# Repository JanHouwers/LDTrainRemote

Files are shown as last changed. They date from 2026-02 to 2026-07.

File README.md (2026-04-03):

# LEGO Duplo Train Remote Control

A custom remote control for the Lego duplo 10427 train, built with a Seeed Studio XIAO ESP32S3 microcontroller. Designed for and tested with the **LEGO DUPLO Train set 10427**. Connects to the train over BLE using raw NimBLE and the LEGO Wireless Protocol 3 (LWP3).

## Hardware

- **Board:** Seeed Studio XIAO ESP32S3
- **Potentiometer** on GPIO2 (D1) for variable speed control
- **4 push buttons** (active low, using internal pull-ups):

| GPIO | Pin | Function |
|---|-----|---|
| 3 | D2  | Water/action sound cycle |
| 4 | D3  | Horn |
| 5 | D4  | Stop (brake) |
| 6 | D5  | LED color cycle |

## Features

- **Variable speed** — potentiometer maps linearly to 0-100% forward or backward, with a 15% deadband around center for stop
- **11 LED colors** — cycle through off, white, green, yellow, light blue, dark blue, purple, purple pink, light pink, red pink, red
- **7 action sounds** — cycle through recorded sound, cat, nothing, beach, rain, birthday, night
- **Horn** — plays the train horn sound
- **Stop button** — immediately stops the motor
- **Auto-reconnect** — automatically scans and reconnects when the train is turned off and back on
- **Debounced buttons** — using the Bounce2 library

## Building & Uploading

Requires [PlatformIO](https://platformio.org/).

```bash
# Compile
pio run

# Upload to board
pio run -t upload

# Serial monitor
pio device monitor
```

## Dependencies

- [NimBLE-Arduino](https://github.com/h2zero/NimBLE-Arduino) 2.x — BLE stack
- [Bounce2](https://github.com/thomasfredericks/Bounce2) — button debouncing

## Configuration

Pin assignments, potentiometer deadband, speed limits, and timing are all configurable in `config.h`.

## Protocol

Communicates with the Duplo Train Hub using raw LEGO Wireless Protocol 3 (LWP3) packets over BLE:
- **Service UUID:** `00001623-1212-efde-1623-785feabcd123`
- **Characteristic UUID:** `00001624-1212-efde-1623-785feabcd123`
- **Motor packet format (11 bytes):** `0B 00 81 34 11 51 01 [CMD] 01 [SPEED] 00`
  - CMD: `01`=forward, `02`=backward, `03`=stop, `04`=LED, `06`=action, `07`=horn

## Acknowledgments

This project is based on the excellent work by [drndos](https://github.com/drndos) and his [duplo-train-controller](https://github.com/drndos/duplo-train-controller). Many thanks for figuring out the BLE protocol, the raw LWP3 packet format, and providing a working NimBLE implementation that made this project possible!

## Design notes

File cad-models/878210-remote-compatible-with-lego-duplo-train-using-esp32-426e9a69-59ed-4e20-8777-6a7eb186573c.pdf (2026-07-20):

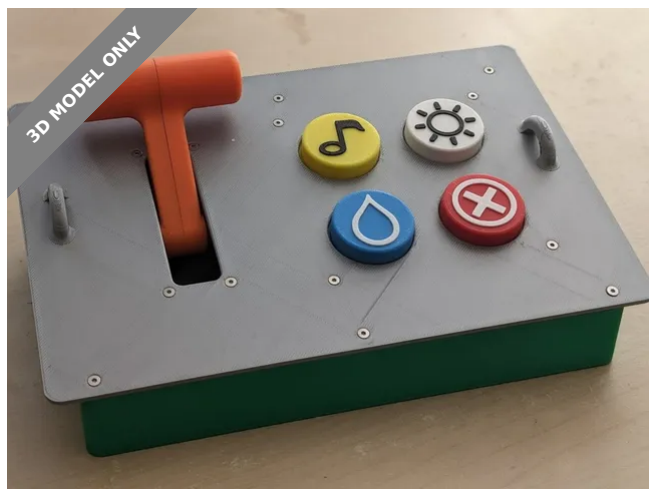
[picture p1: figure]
3D MODEL ONLY

## Summary

Remote compatible with Lego Duplo Train Introduction This project is an adaptation of the work by James Clarke, as...

Toys & Games (https://printables.com/model?categoryId=30) > Building Toys (https://printables.com/model?categoryId=37)

Tags: | duplo | lego | remotecontrol | legocompatible | legoduplo
duplotrain | legoduplotrain

Remote compatible with Lego Duplo Train
Introduction

This project is an adaptation of the work by James Clarke, as showcased on Instructables: https://www.instructables.com/Wooden-Bluetooth-Remotefor-Lego-Duplo-Train/ (https://www.instructables.com/Wooden-Bluetooth-Remote-for-Lego-Duplo-Train/)

I appreciate and thank him for the great idea that inspired this project.

The Lego Duplo Train Remote is a fantastic way to engage with and enjoy the Lego Duplo Train.

Mav_ (https://printables.com/@Mav__1866170)

## Remote compatible with Lego Duplo Train using ESP32

VIEW IN BROWSER (https://printables.com/model/878210-remote-compatible-with-lego-duplo-train-using-esp3)

updated 2. 12. 2024 | published 2. 12. 2024

Custom Section

Step 1:
Electronics and additional parts you need for this project:

1x ESP32 with 18650 Battery holder (ESP-Wroom-ESP32 NOT ESPWROOM-02) https://www.walmart.com/ip/ESP32-WiFi-Bluetooth-Development-Board-Small-IoT-Device-Compatible-With-18650-Battery-For-Programming-Projects-Wireless-Communication-Modu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 (https://www.walmart.com/ip/ESP32-WiFi-Bluetooth-Development-Board-Small-IoT-Device-Compatible-With-18650-Battery-For-Programming-Projects-Wireless-Communicati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)

4x Tactile Push Buttons 12x12x7.3mm https://www.amazon.com/TWTADE-Momentary-Tactile-Button-12x12x12mm/dp/B07CG7VTGD/ref=sr_1_5 (https://www.amazon.com/TWTADE-Momentary-Tactile-Button-12x12x12mm/dp/B07CG7VTGD/ref=sr_1_5)

1x Potentiometer 10k Ohm https://www.amazon.com/HiLetgo-Single-Joint-Potentiometer-Variable-Resistors/dp/B00MCK7JMS/ref=sr_1_1_sspa (https://www.amazon.com/HiLetgo-Single-Joint-Potentiometer-Variable-Resistors/dp/B00MCK7JMS)

Set of Electric wires https://www.amazon.com/StrivedayTM-Flexible-Silicone-electronic-electrics/dp/B01LH1FYR4/ref=sr_1_1_sspa (https://www.amazon.com/StrivedayTM-Flexible-Silicone-electronic-electrics/dp/B01LH1FYR4)

18x melting Nuts m2 3.5mm in diameter (3.2 might also work) https://www.amazon.com/WALENI-Knurled-Injection-Embedment-Insertion/dp/B0CC8BZHZL/ref=sr_1_5?th=1 (https://www.amazon.com/WALENI-Knurled-Injection-Embedment-Insertion/dp/B0CC8BZHZL/ref=sr_1_5?th=1)

18 m2 x 6mm countersunk head screws https://www.amazon.com/Hilitchi-210-Piece-Metric-Countersunk-Assortment/dp/B06Y3M62Z8/ref=sr_1_6 (https://www.amazon.com/Hilitchi-210-Piece-Metric-Countersunk-Assortment/dp/B06Y3M62Z8/ref=sr_1_6)

1 Power Switch https://www.amazon.de/dp/B08CY41YT5?ref=ppx_yo2ov_dt_b_product_details&th=1 (https://www.amazon.de/dp/B08CY41YT5?ref=ppx_yo2ov_dt_b_product_details&th=1)

the size of power switches varies ... so you might need to update the body STL for the right size. I ordered these in Germany the hole in the body STL is 12 * 19 mm.

Other:

Some glue for the throttle stick (optional)

Small piece of perfboard (optional)

Some shrink tubing (recommended)

Filament:

I used PLA in 8 different colors:

- Green for the housing,

Silver top plate,
Red for the Stop push button (with white),
Blue for the Steam/Water push button (with white) Yellow for the Horn/Music push button (with black), White for the Light push button ( with black)
Black for holders (buttons and throttle lever holder), Orange for the throttle lever

In addition you need:

a soldering iron with solder,
the right screwdriver for the m2 screws
some tools to cut the cables and to strip the cables insulation.
Step 2:
3D Print all parts

Print all the parts in the color of your choice.

Please note that the throttle stick needs to be printed twice, while all other parts only need to be printed once.

All Parts

Step 3:
Soldering the ElectronicsSolder ground:

You will need 5 ground connections: 4 for the buttons and 1 for the potentiometer. Locate the ground pin on your ESP32 board and solder a small cable, around 5-10 cm in length, to it. Connect the other end of this cable to a piece of perfboard where you will solder an additional 5 cables, each around 10-20 cm in length.

(Another solution would be to daisy chain the ground cable: ESP32 GND -> potentiometer GND -> Button 1 GND -> Button 2 GND, and so on.)

PICTURE SOLDER Power Switch

GND cable harness

GND to ESP32
Solder GPIOs

Solder 6 cables, each approximately 15-25 cm in length, to the following ESP32 pins:

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
Pin 25: Button 1 (Yellow)

Pin 26: Button 2 (White)

Pin 27: Button 3 (Blue)

Pin 14: Button 4 (Red)

Pin 15: Potentiometer Data (Green)

VCC: Potentiometer + (Red)

... and connect them

*I have matched the colors of the buttons for a clear view, but you can use any colors you prefer.

Buttons & Poti

GPIO soldering
Power Switch:

Before soldering, it is important to either attach the power switch directly to the 3D printed body or use ferrules that fit the power switch.

Power Switch: On the side of the ESP32 board, there is a power switch attached. To bypass it, you need solder the new Power Switch to the left pin (ON) and the middle pin. Make sure to leave the switch on the board in the off position. A cable length of approximately 25 cm will be sufficient.

power switch

Power Switch soldering

Step 4:
Assemble all parts.Inserting Melting Nuts:

To assemble the body, you will need to fuse in a total of 10 melting nuts. Six of these nuts are used to connect the top plate, while the remaining four are for attaching the ESP32. Additionally, the button holder requires four melting nuts to be attached to the top plate as well as the Throttle sick holder.

Melt Nuts

Melt Nuts

ESP32:

Screw the ESP32 onto the body.

Optional: Attach 18650 battery to ESP32 board.
Throttle Assembly:

Begin by inserting the potentiometer into the throttle stick holder. Ensure that the potentiometer is set to the middle position, although adjustments may be necessary in the software.
Next, insert the right part of the throttle stick and connect it with the potentiometer. Pass throttle stick through the top plate throttle stick hole.
The left throttle stick may require a bit more effort and force to insert, also pass it though the top plate. The Holder will need to stretch a bit. Optionally, connect the stick halves with a small bar and consider using glue to secure them together.
Screw the holder onto the top plate.

Poti

Throttle Stick #1

Throttle Stick #2

Throttle Stick #3
Button Assembly:

The push buttons need to be placed on top of the button plate. Thread the buttons through the holes in the plate. In this step, you need to determine the correct placement for each button
Connect the 3D printed buttons to the push buttons.
Screw the button plate onto the top plate.

Buttons

Buttons

Hardware Finished

Step 5:
Flash the Software

To flash the software onto the ESP32, follow these steps:

Download the software from GitHub. You can find it here. (https://github.com/mav00/LDTrainRemote)

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
## Model files

The software requires the Leguino Library, which you can download from here. (https://github.com/corneliusmunz/legoino?tab=readme-ov-file)
Additionally, the software requires the Button2 Library, which doesn't need to be downloaded separately.
You have two options to flash the software: PlatformIO or Arduino IDE.

PlatformIO:

Install PlatformIO plugin in Visual Studio Code (Picture1)
Restart Visual Studio Code when everything is finished (Picture2) Pick the LDTTRAINREMOTE Folder ( not the SRC folder but the folder above)
Copy legoino-master into a fresh created "lib" folder next to the src folder (Picture3)
check spelling legoino-master in platformio.ini file ... sorry I will update the code (Picture3)
VS Code will install some prerequisites- wait until it is finished ... takes about (Picture4)
goto src / main.cpp hit build (the check icon in the lower bar) upload the code with the -> icon
Step 6:
Enjoy ...Activate the Remote:

Power up the Train. The Lego Duplo Train searches for Bluetooth connection for about 20 seconds after powering up
Start the Remote by switching it on.
The train will give a sound when it is successfully connected to the remote.

Category: Toy & Game Accessories

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
rldt_-_button_light_v10.stl

rldt_-_throttle_stick_holder_v10.stl

Find source .stl files on Thingiverse.com (https://www.thingiverse.com/thing:6620027) rldt_-_button_water_v10.stl

rldt_-_throttle_stick_v10.stl

rldt_-__button_holder_v10.stl

rldt_-_body_v10.stl

rldt_-_throttle_stick_connection_rod_v10.stl

rldt_-_button_stop_v10.stl

rldt_-_button_music_v10.stl

rldt_-_topplate_v10.stl

## License

This work is licensed under a
Creative Commons (4.0 International License)

Attribution—Noncommercial—Share Alike (http://creativecommons.org/licenses/by-nc-sa/4.0/)

✖ | Sharing without ATTRIBUTION
✔ | Remix Culture allowed
✖ | Commercial Use
✖ | Free Cultural Works
✖ | Meets Open Definition

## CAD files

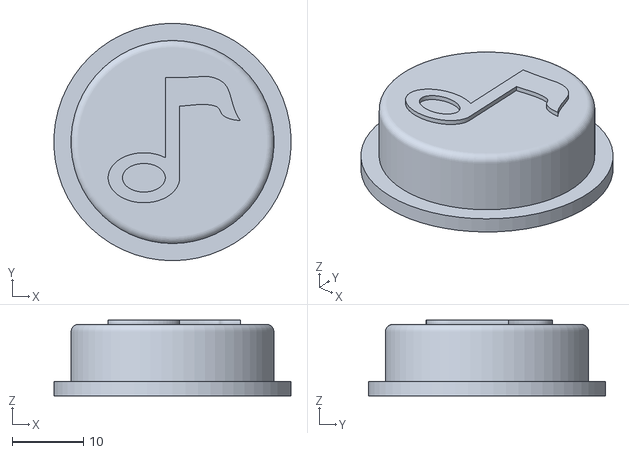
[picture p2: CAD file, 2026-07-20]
cad-models/rldt_-_button_music_v10.stl
33.2 x 33.2 x 10.6

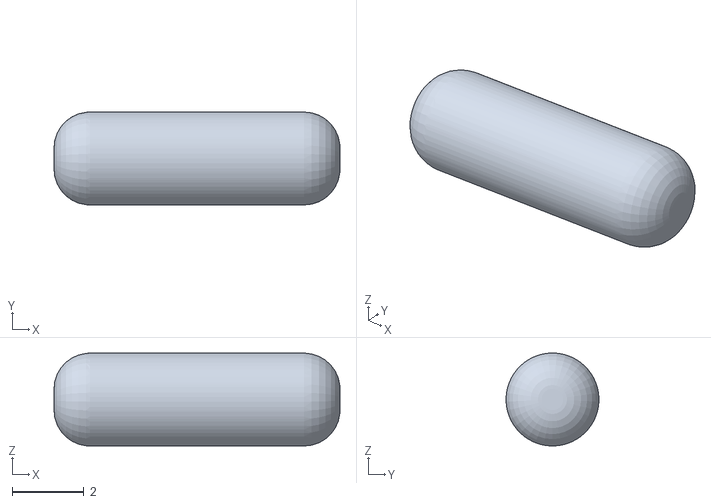
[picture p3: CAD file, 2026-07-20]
cad-models/rldt_-_throttle_stick_connection_rod_v10.stl
8.00 x 2.60 x 2.60

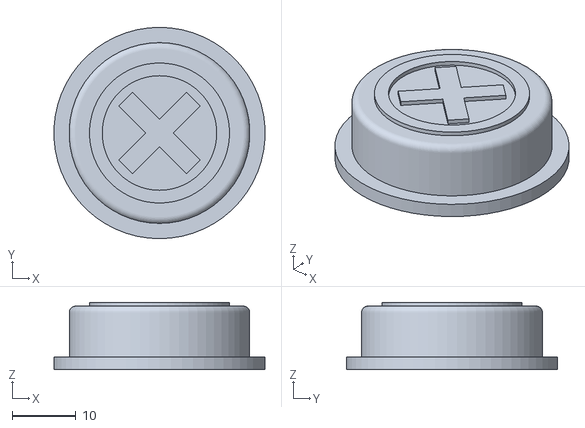
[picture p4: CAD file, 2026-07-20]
cad-models/rldt_-_button_stop_v10.stl
33.2 x 33.2 x 10.6

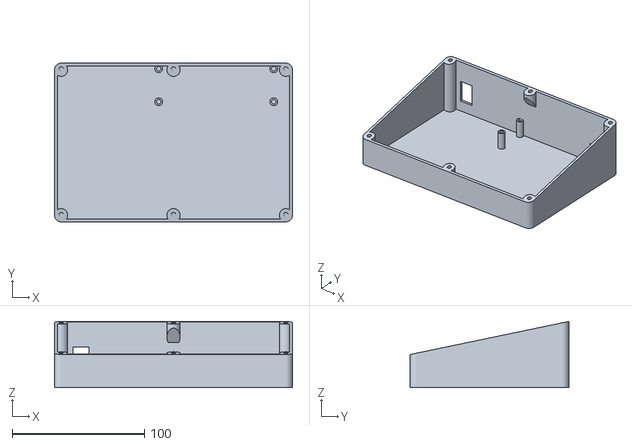
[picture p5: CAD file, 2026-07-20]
cad-models/rldt_-_body_v10.stl
180.0 x 120.0 x 50.0

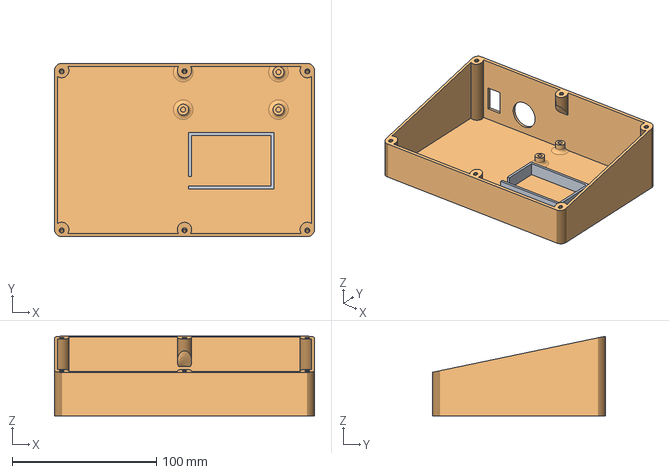
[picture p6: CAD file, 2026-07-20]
cad-models/BOX SC V2.stp
180.0 x 120.0 x 55.1 mm
Design1
rldt_-_body_v10

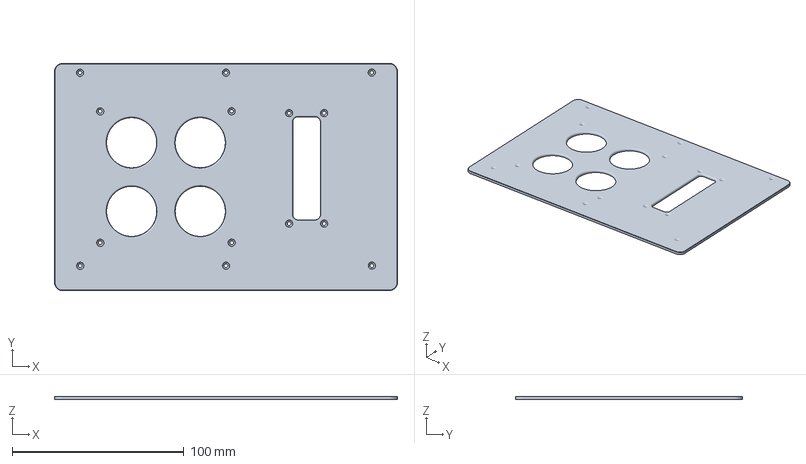
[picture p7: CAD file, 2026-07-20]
cad-models/topplaat.scdocx.3mf
199.9 x 132.5 x 2.00 mm

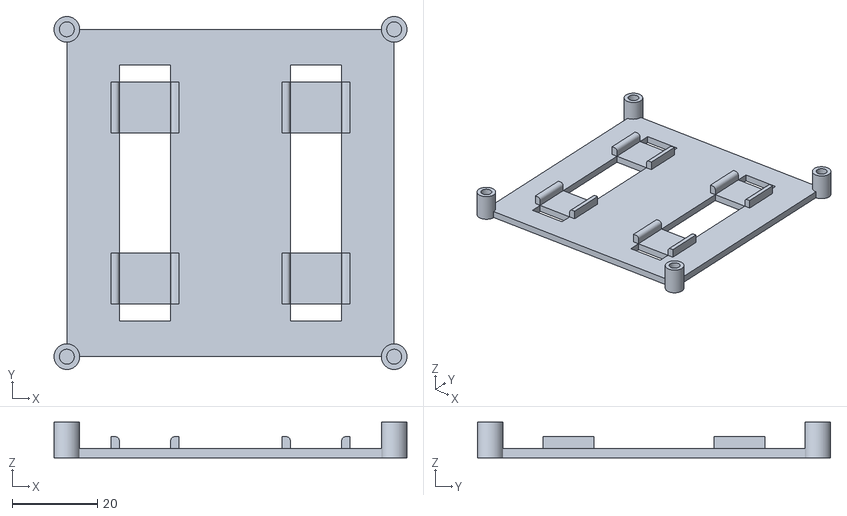
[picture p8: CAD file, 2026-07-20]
cad-models/rldt_-__button_holder_v10.stl
82.6 x 82.6 x 8.40

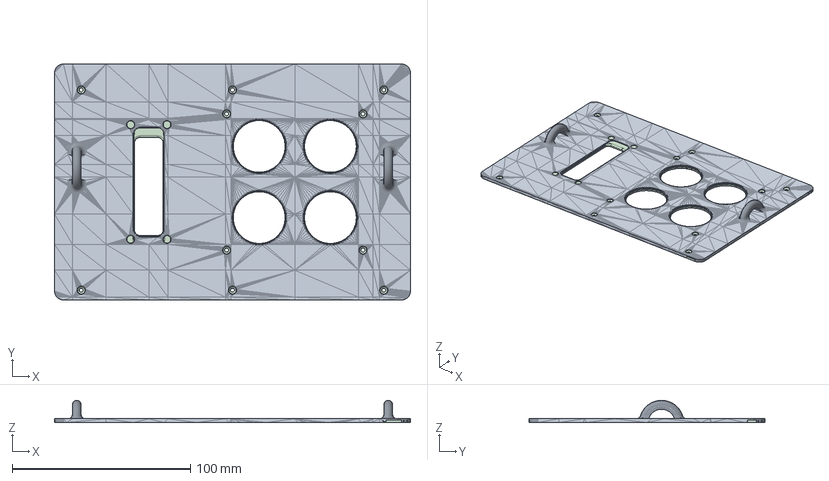
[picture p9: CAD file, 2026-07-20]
cad-models/Topplaat.stp
200.0 x 132.6 x 12.5 mm
Design2
rldt_-_topplate_v10
Topplaat

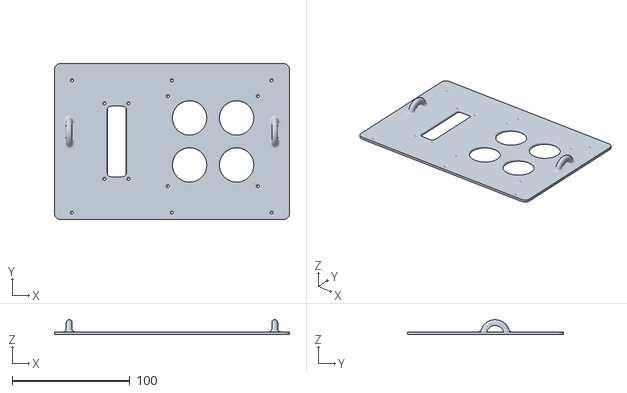
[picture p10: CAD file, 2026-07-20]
cad-models/rldt_-_topplate_v10.stl
200.0 x 132.6 x 12.5

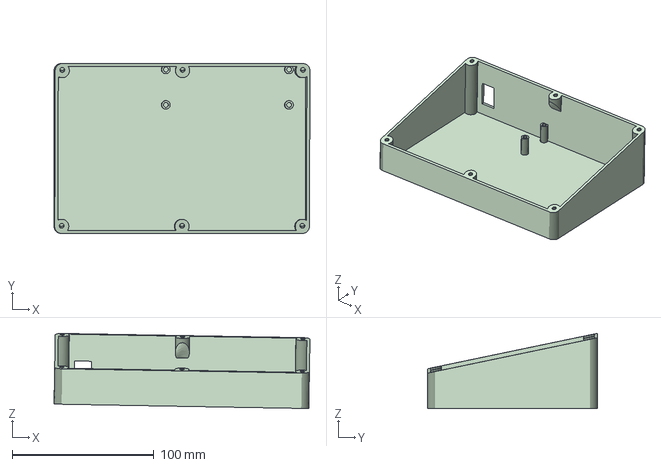
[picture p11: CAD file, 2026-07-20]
cad-models/box.stp
180.8 x 120.0 x 53.0 mm

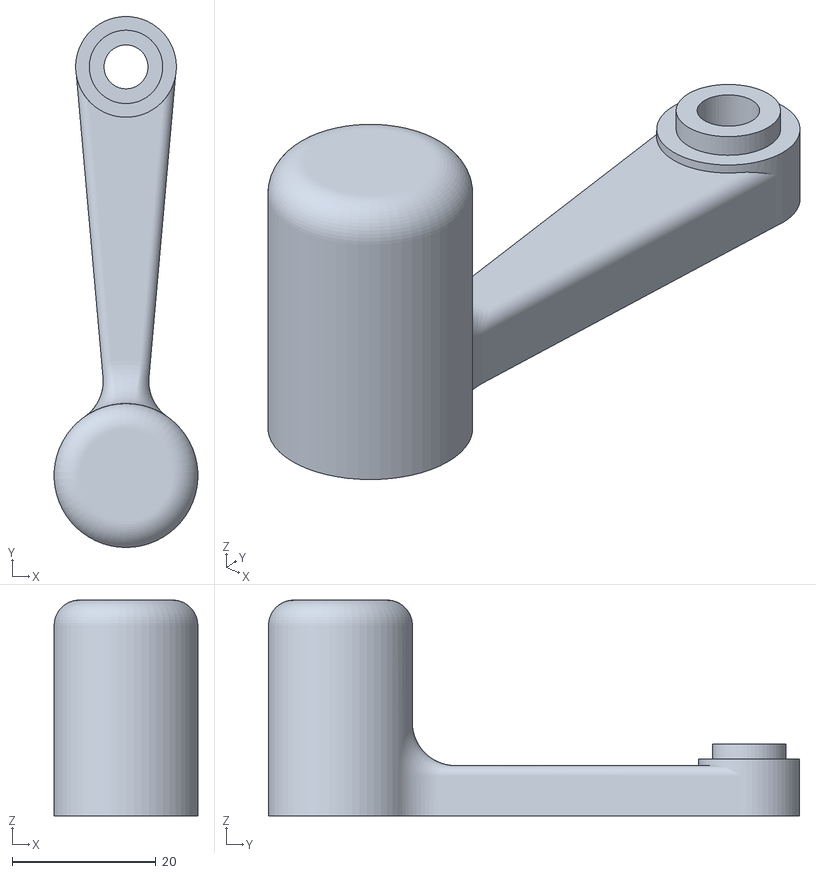
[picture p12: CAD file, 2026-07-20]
cad-models/rldt_-_throttle_stick_v10.stl
20.0 x 73.8 x 30.0

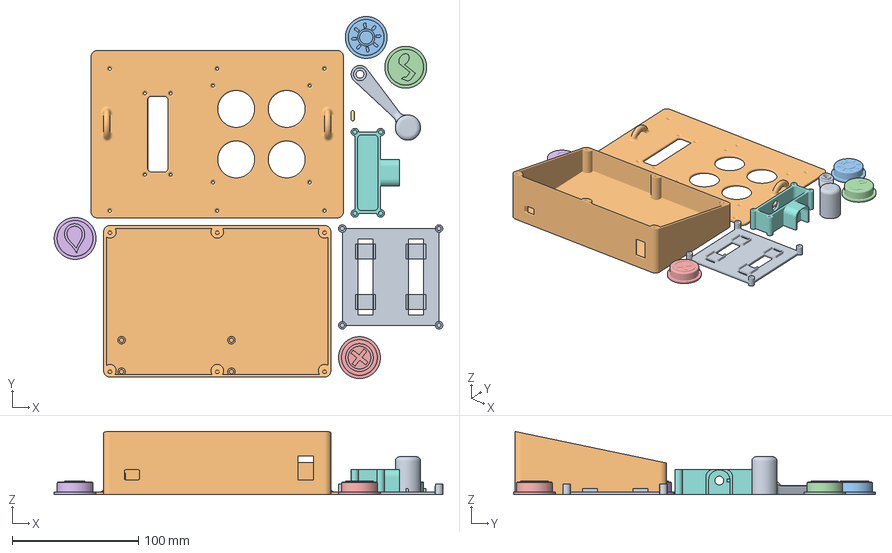
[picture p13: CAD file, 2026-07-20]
cad-models/alle delen.3mf
307.7 x 286.7 x 50.0 mm
rldt_-__button_holder_v10.stl
rldt_-_body_v10.stl
rldt_-_button_light_v10.stl
rldt_-_button_music_v10.stl
rldt_-_button_stop_v10.stl
rldt_-_button_water_v10.stl
rldt_-_throttle_stick_connection_rod_v10.stl
rldt_-_throttle_stick_holder_v10.stl
rldt_-_throttle_stick_v10.stl
rldt_-_topplate_v10.stl

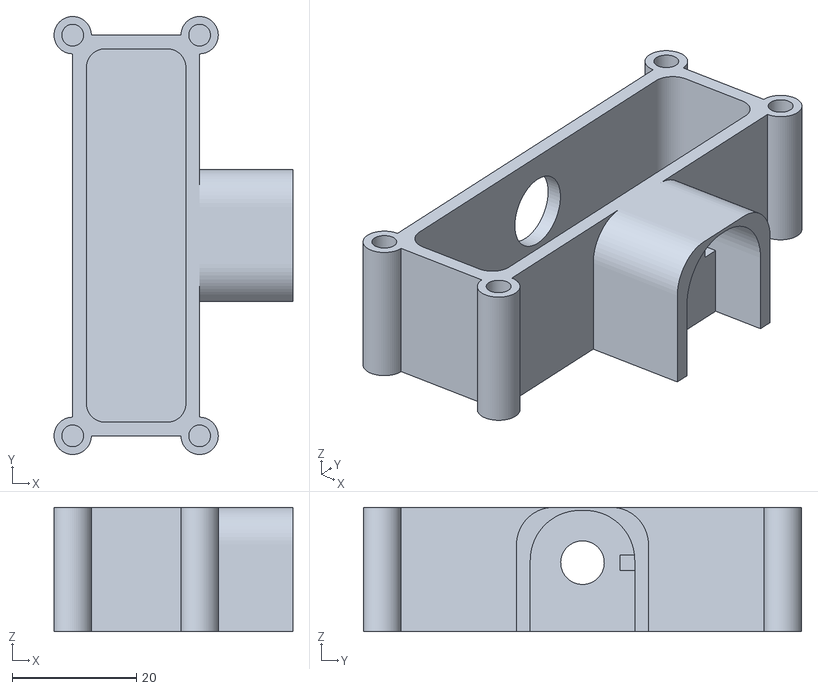
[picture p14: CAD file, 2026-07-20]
cad-models/rldt_-_throttle_stick_holder_v10.stl
38.4 x 70.4 x 20.0

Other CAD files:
cad-models/box moi.stp
cad-models/rldt_-_button_water_v10.stl
cad-models/rldt_-_button_light_v10.stl
cad-models/BOX SC v2.3mf
cad-models/box moi.3dm

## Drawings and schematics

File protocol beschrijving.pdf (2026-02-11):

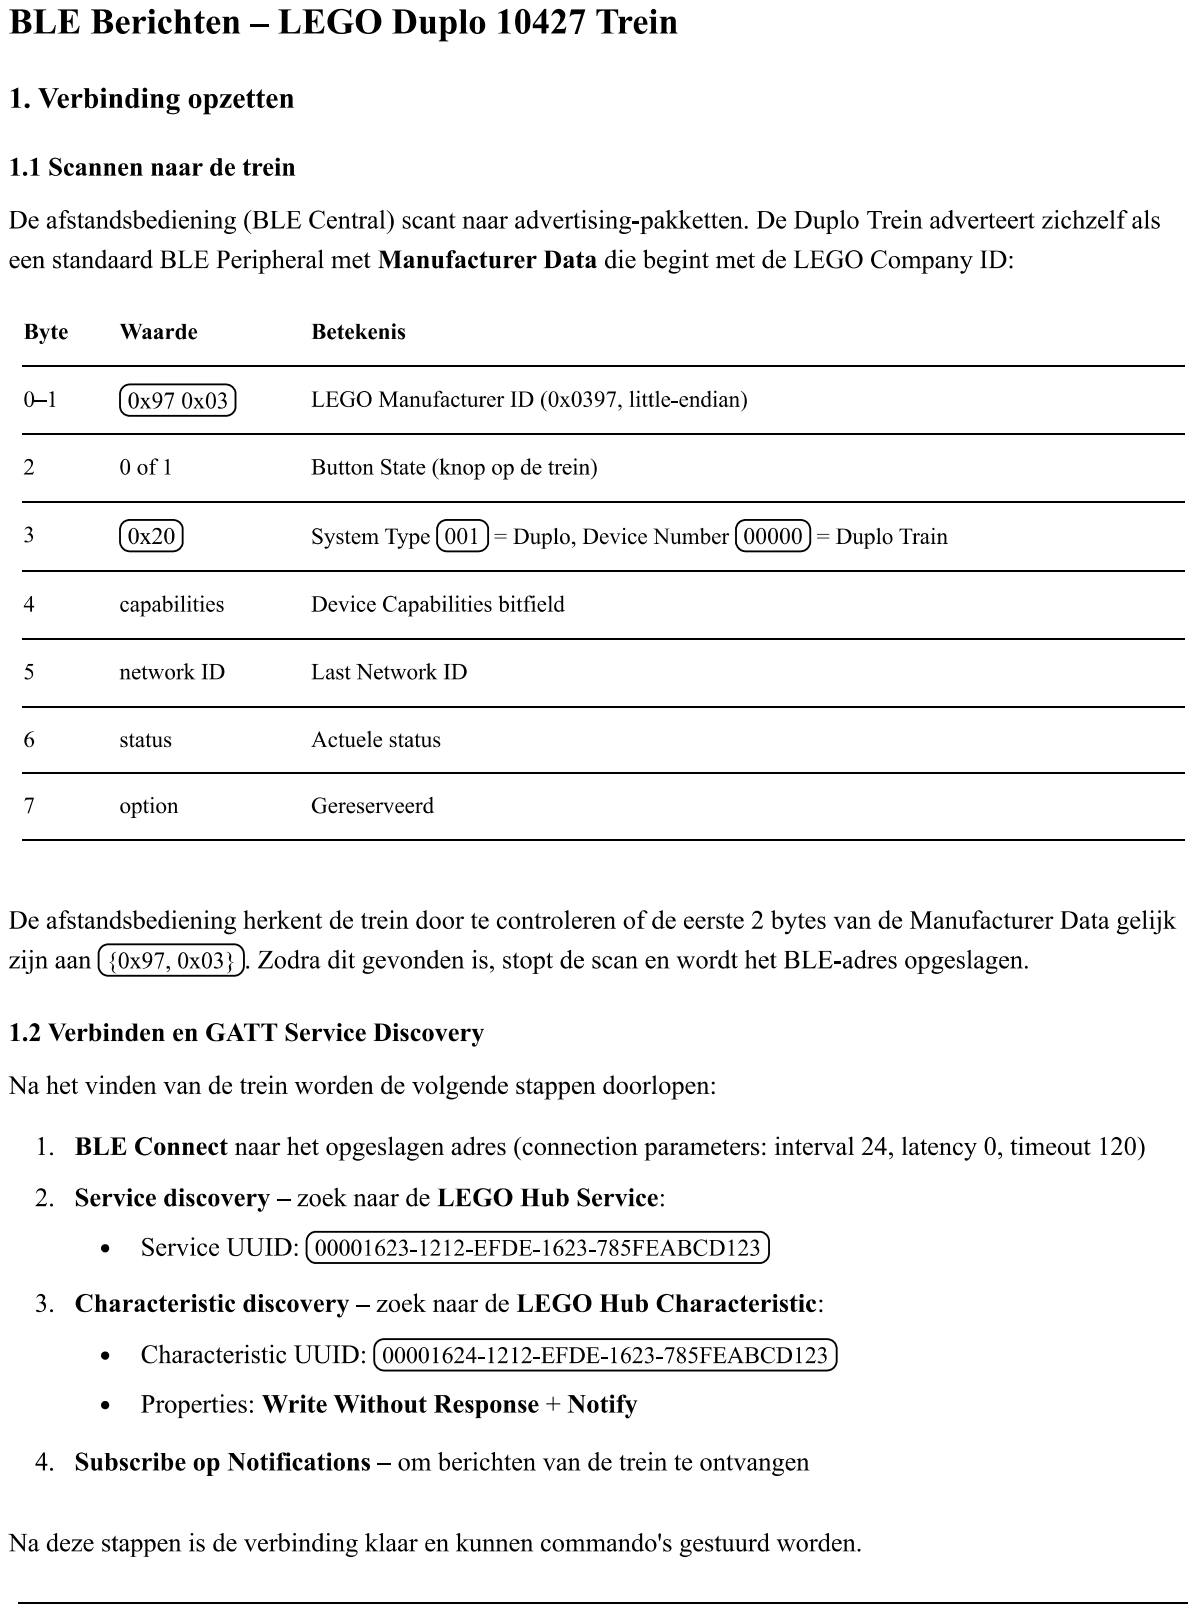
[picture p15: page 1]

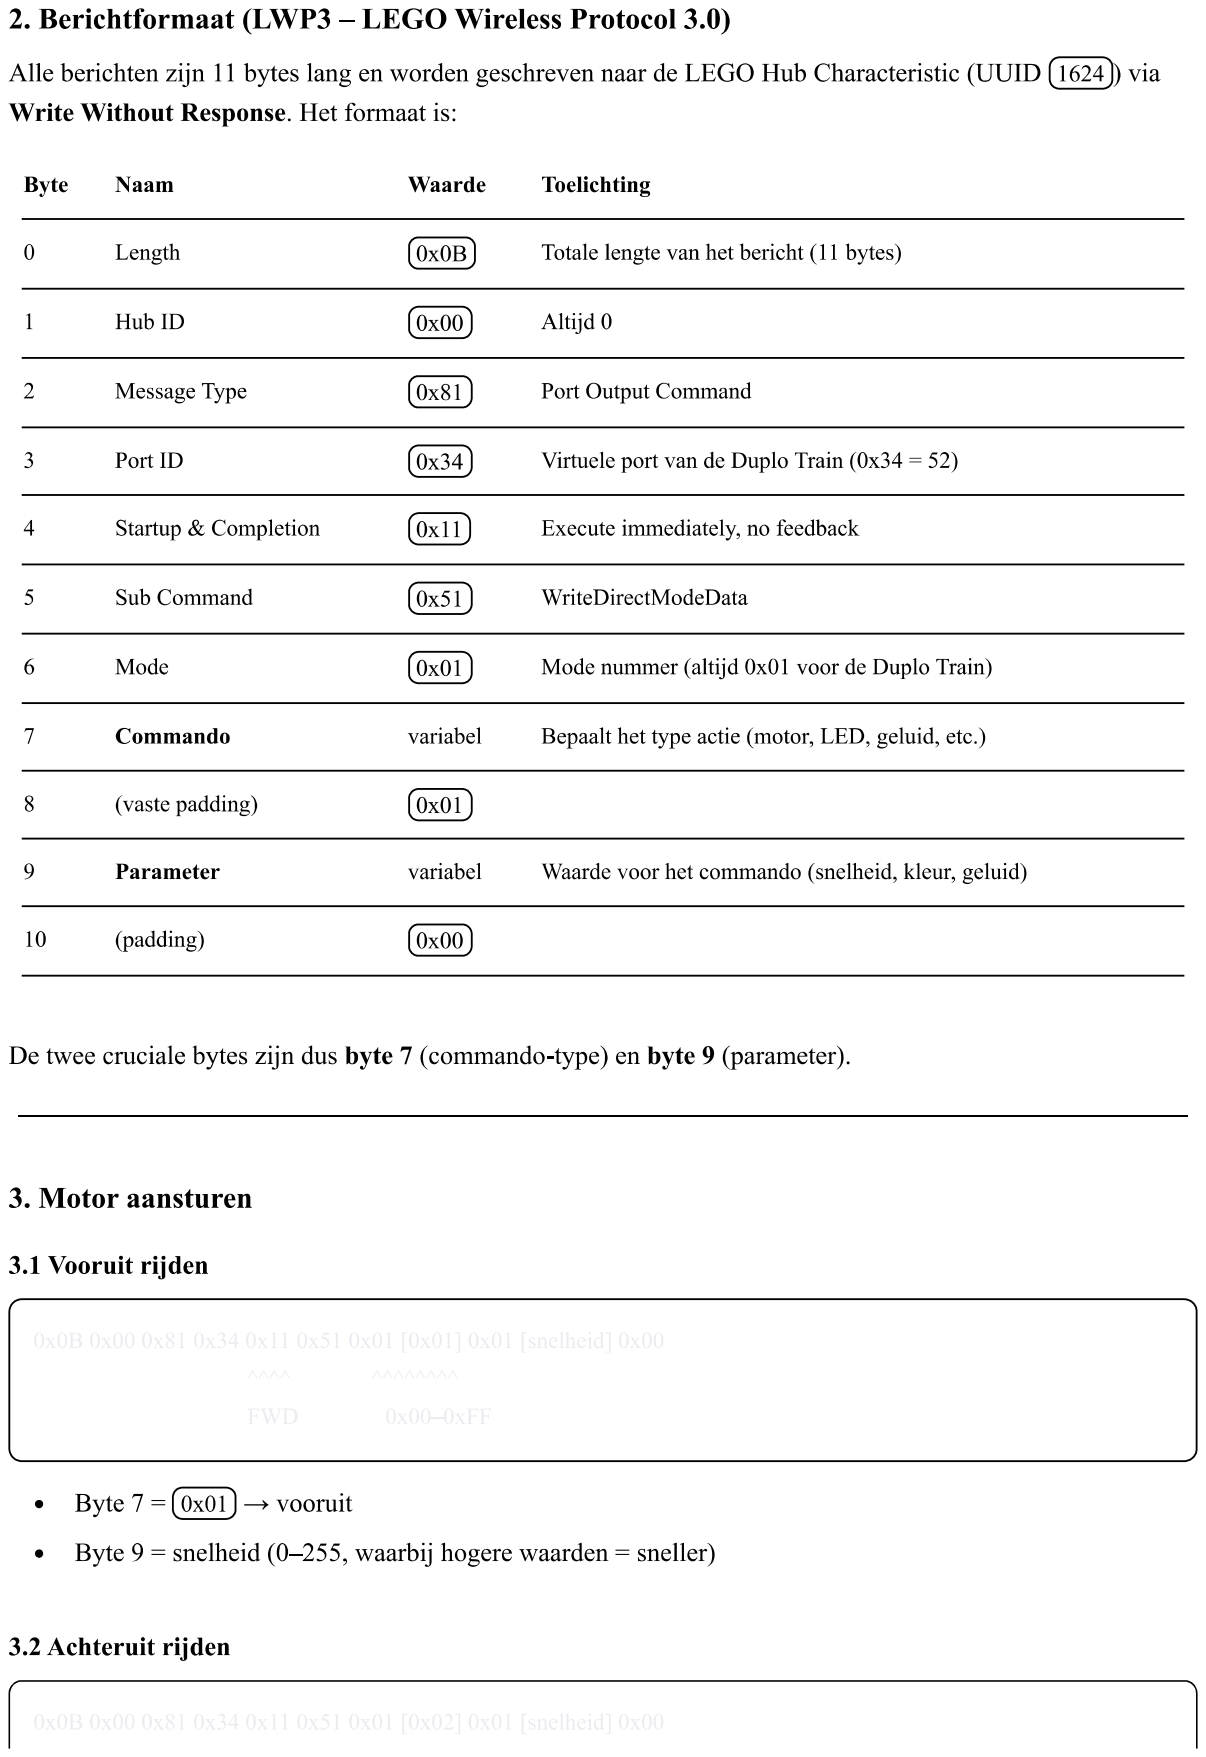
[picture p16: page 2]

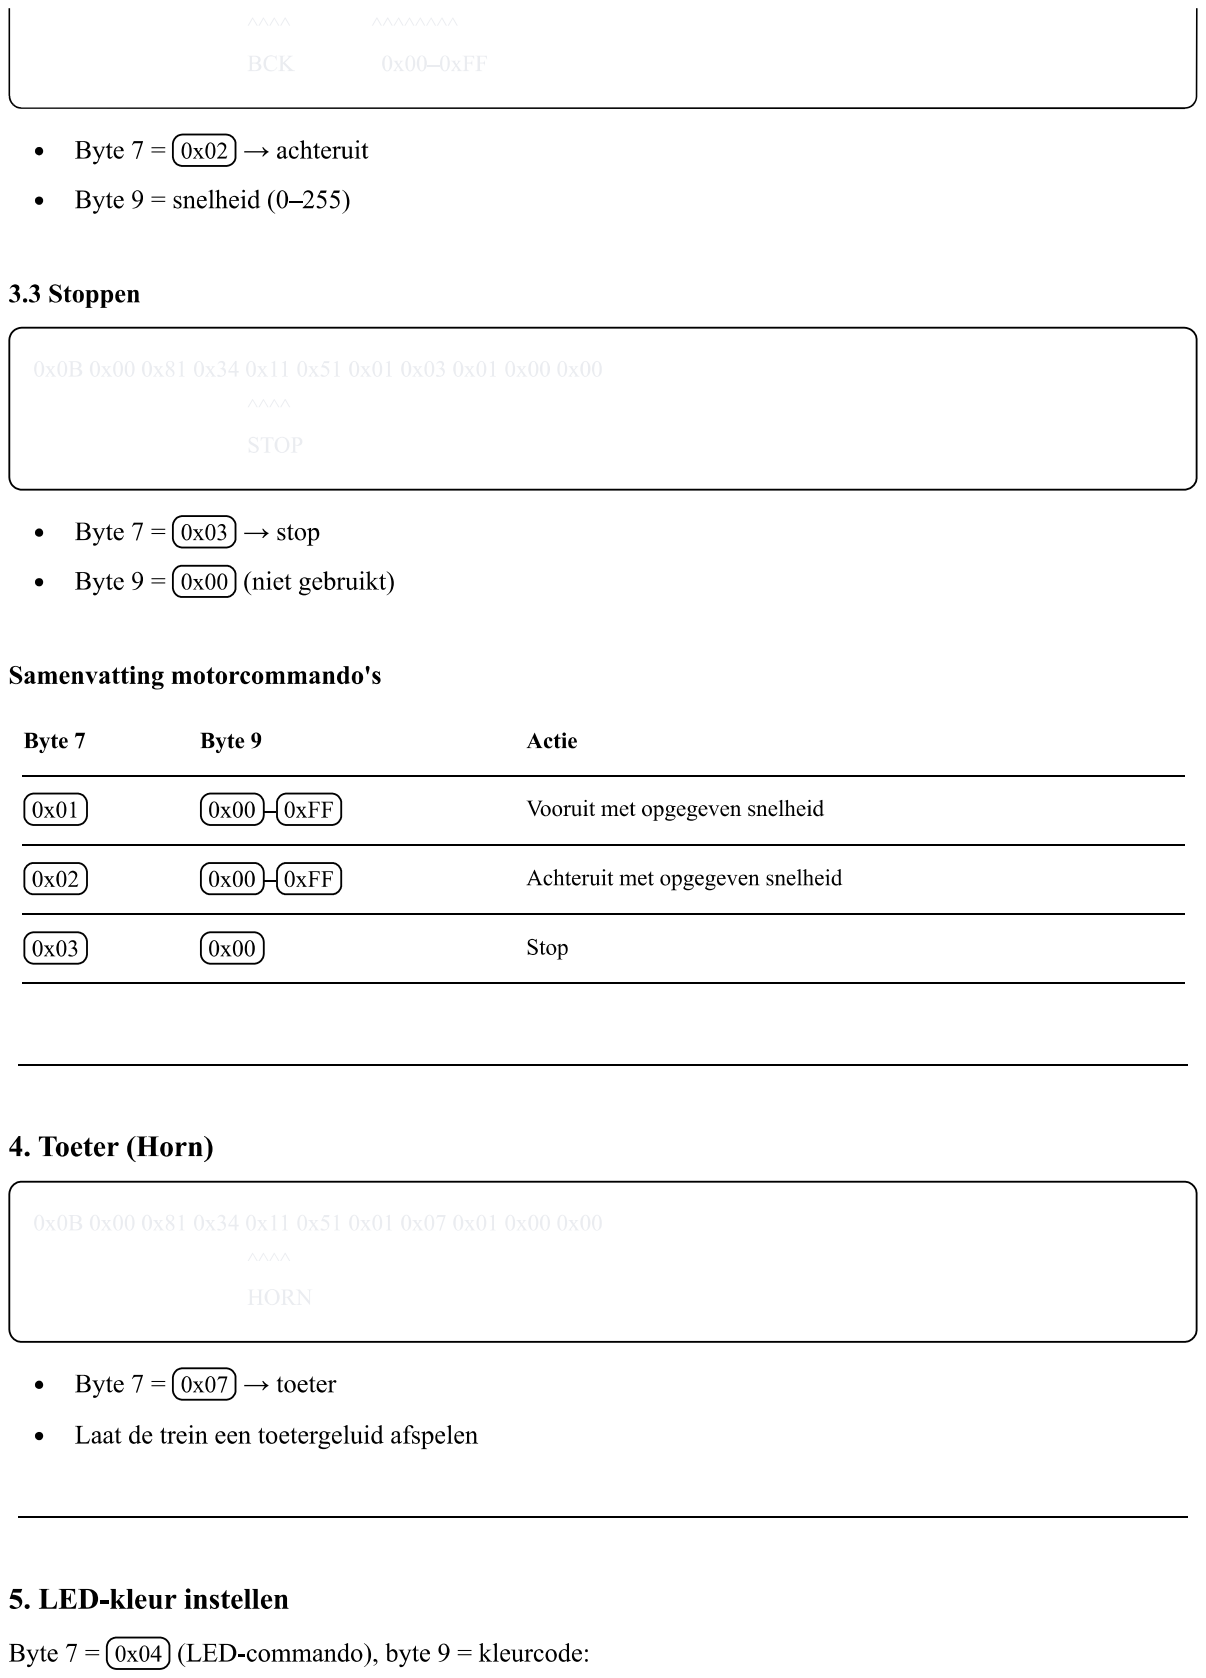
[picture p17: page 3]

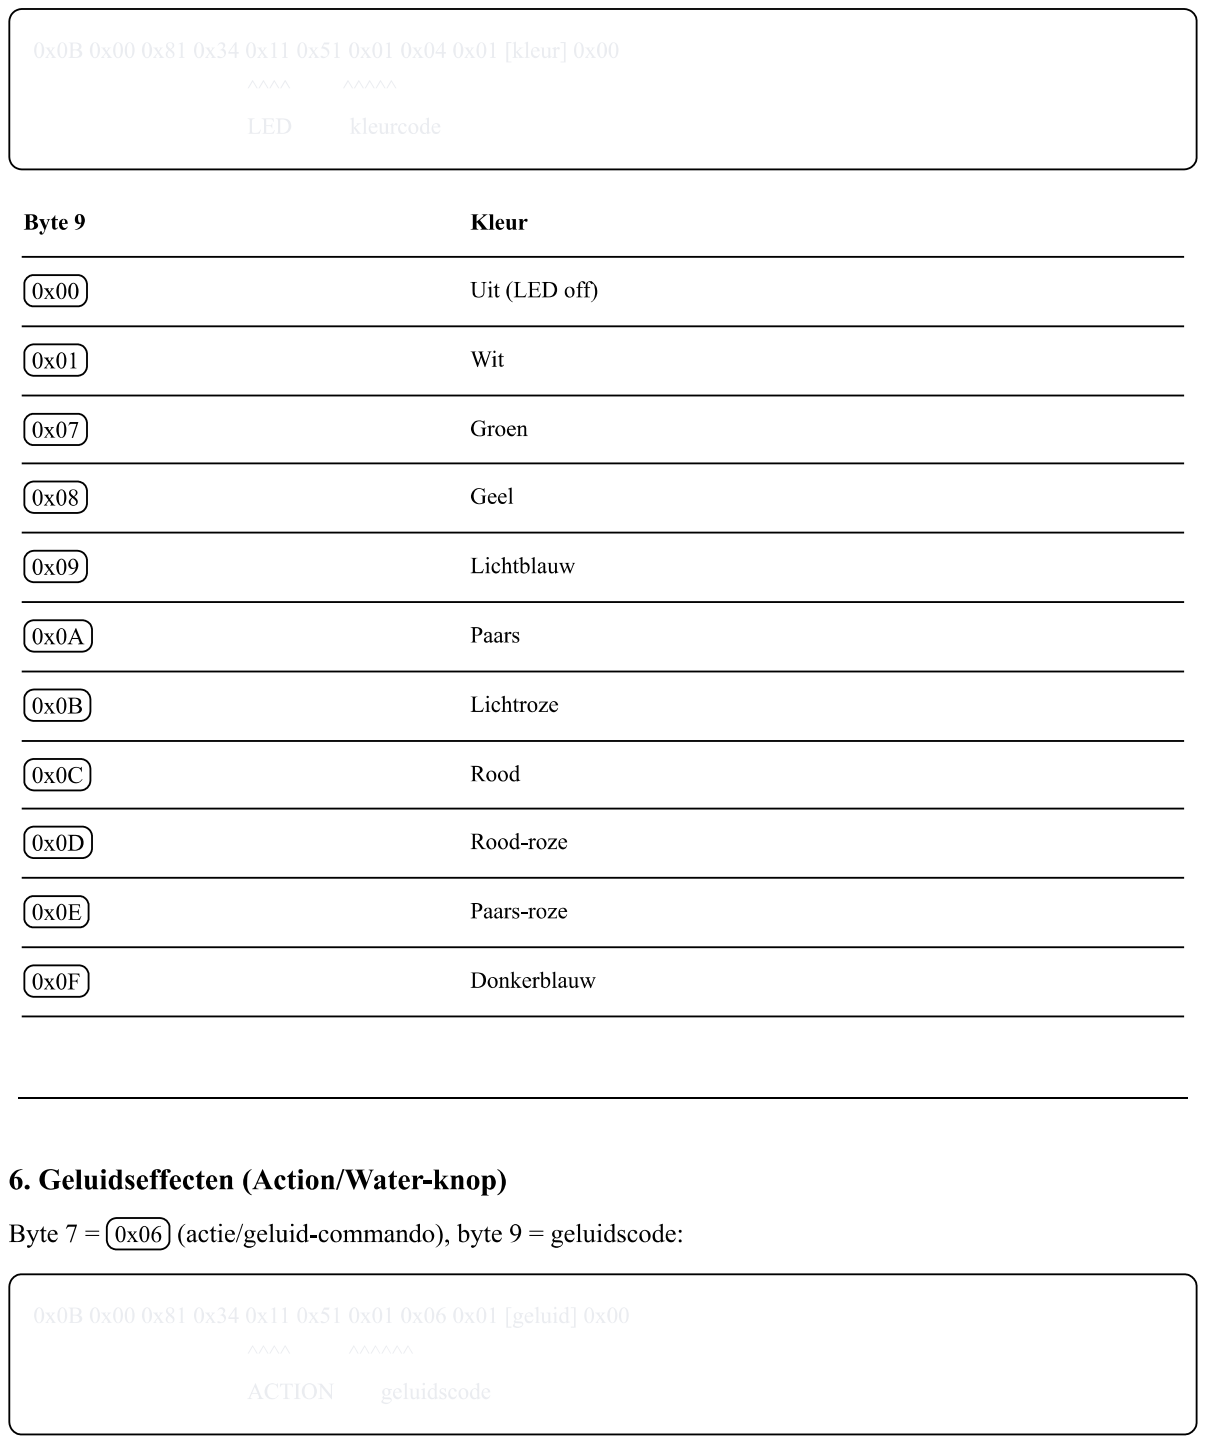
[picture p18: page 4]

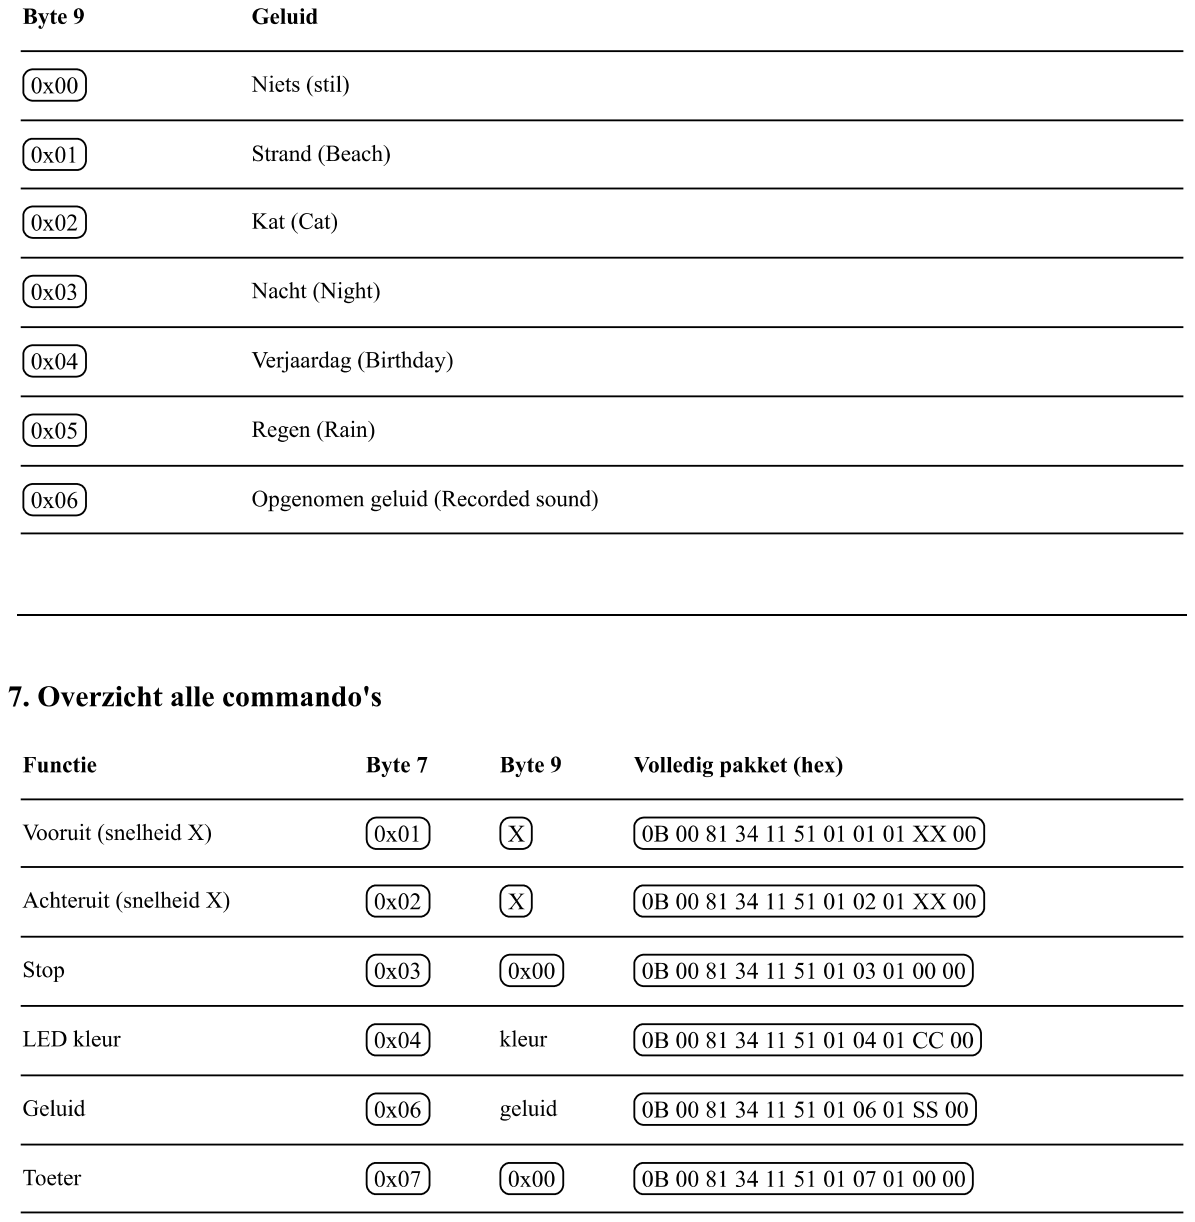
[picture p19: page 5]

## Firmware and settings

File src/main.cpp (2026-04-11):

#include <Arduino.h>
#include <NimBLEDevice.h>
#include <Bounce2.h>
#include <esp_sleep.h>
#include "../config.h"

// ── LEGO Wireless Protocol ──────────────────────────────
static NimBLEUUID kServiceUuid("00001623-1212-efde-1623-785feabcd123");
static NimBLEUUID kCharUuid("00001624-1212-efde-1623-785feabcd123");
static const uint8_t kLegoMfgPrefix[] = {0x97, 0x03};

// ── Raw LWP3 Packets ────────────────────────────────────
// Motor: byte[7]=command (0x01=fwd, 0x02=bck, 0x03=stop), byte[9]=speed
static uint8_t kMotorPacket[] = {0x0B, 0x00, 0x81, 0x34, 0x11, 0x51, 0x01, 0x01, 0x01, 0x00, 0x00};
static const uint8_t kStopPacket[] = {0x0B, 0x00, 0x81, 0x34, 0x11, 0x51, 0x01, 0x03, 0x01, 0x00, 0x00};
static const uint8_t kHornPacket[] = {0x0B, 0x00, 0x81, 0x34, 0x11, 0x51, 0x01, 0x07, 0x01, 0x00, 0x00};

// LED color packets: byte[9] = color code
static const uint8_t kLedPackets[][11] = {
    {0x0B, 0x00, 0x81, 0x34, 0x11, 0x51, 0x01, 0x04, 0x01, 0x00, 0x00}, // Off
    {0x0B, 0x00, 0x81, 0x34, 0x11, 0x51, 0x01, 0x04, 0x01, 0x01, 0x00}, // White
    {0x0B, 0x00, 0x81, 0x34, 0x11, 0x51, 0x01, 0x04, 0x01, 0x07, 0x00}, // Green
    {0x0B, 0x00, 0x81, 0x34, 0x11, 0x51, 0x01, 0x04, 0x01, 0x08, 0x00}, // Yellow
    {0x0B, 0x00, 0x81, 0x34, 0x11, 0x51, 0x01, 0x04, 0x01, 0x09, 0x00}, // Light Blue
    {0x0B, 0x00, 0x81, 0x34, 0x11, 0x51, 0x01, 0x04, 0x01, 0x0F, 0x00}, // Dark Blue
    {0x0B, 0x00, 0x81, 0x34, 0x11, 0x51, 0x01, 0x04, 0x01, 0x0A, 0x00}, // Purple
    {0x0B, 0x00, 0x81, 0x34, 0x11, 0x51, 0x01, 0x04, 0x01, 0x0E, 0x00}, // Purple Pink
    {0x0B, 0x00, 0x81, 0x34, 0x11, 0x51, 0x01, 0x04, 0x01, 0x0B, 0x00}, // Light Pink
    {0x0B, 0x00, 0x81, 0x34, 0x11, 0x51, 0x01, 0x04, 0x01, 0x0D, 0x00}, // Red Pink
    {0x0B, 0x00, 0x81, 0x34, 0x11, 0x51, 0x01, 0x04, 0x01, 0x0C, 0x00}, // Red
};
static const size_t kNumLedColors = sizeof(kLedPackets) / sizeof(kLedPackets[0]);

// Action/water packets: byte[9] = action code
static const uint8_t kActionPackets[][11] = {
    {0x0B, 0x00, 0x81, 0x34, 0x11, 0x51, 0x01, 0x06, 0x01, 0x06, 0x00}, // Recorded sound
    {0x0B, 0x00, 0x81, 0x34, 0x11, 0x51, 0x01, 0x06, 0x01, 0x02, 0x00}, // Cat
    {0x0B, 0x00, 0x81, 0x34, 0x11, 0x51, 0x01, 0x06, 0x01, 0x00, 0x00}, // Nothing
    {0x0B, 0x00, 0x81, 0x34, 0x11, 0x51, 0x01, 0x06, 0x01, 0x01, 0x00}, // Beach
    {0x0B, 0x00, 0x81, 0x34, 0x11, 0x51, 0x01, 0x06, 0x01, 0x05, 0x00}, // Rain
    {0x0B, 0x00, 0x81, 0x34, 0x11, 0x51, 0x01, 0x06, 0x01, 0x04, 0x00}, // Birthday
    {0x0B, 0x00, 0x81, 0x34, 0x11, 0x51, 0x01, 0x06, 0x01, 0x03, 0x00}, // Night
};
static const size_t kNumActions = sizeof(kActionPackets) / sizeof(kActionPackets[0]);

// ── BLE State ────────────────────────────────────────────
static NimBLEAddress g_targetAddr;
static bool g_haveTarget = false;
static NimBLEClient *g_client = nullptr;
static NimBLERemoteCharacteristic *g_char = nullptr;
static bool g_scanRunning = false;
static unsigned long g_lastScanLogMs = 0;
static uint32_t g_advSeen = 0;

// ── UI State ─────────────────────────────────────────────
static Bounce pbStop = Bounce();
static Bounce pbHorn = Bounce();
static Bounce pbLed = Bounce();
static Bounce pbWater = Bounce();

static size_t g_ledIndex = 0;
static size_t g_actionIndex = 0;
static int g_lastSpeed = 0; // last sent speed: positive=fwd, negative=bck, 0=stop

// ── Inactivity / Deep Sleep ─────────────────────────────
static unsigned long g_lastActivityMs = 0;
static int g_lastPotRaw = 0;

// Forward declaration
static void cleanupClient();

static void resetActivityTimer() {
    g_lastActivityMs = millis();
}

static void enterDeepSleep() {
    Serial.println("Inactivity timeout — entering deep sleep");
    Serial.flush();

    // Disconnect BLE cleanly
    if (g_client && g_client->isConnected()) {
        g_client->disconnect();
    }
    cleanupClient();
    NimBLEDevice::getScan()->stop();
    NimBLEDevice::deinit(true);

    // Wake on any button press (active-low)
    const uint64_t wakeupMask = (1ULL << BTN_STOP_PIN)
                              | (1ULL << BTN_HORN_PIN)
                              | (1ULL << BTN_LED_PIN)
                              | (1ULL << BTN_WATER_PIN);
    esp_sleep_enable_ext1_wakeup(wakeupMask, ESP_EXT1_WAKEUP_ANY_LOW);

    esp_deep_sleep_start();
}

// ── BLE Helpers ──────────────────────────────────────────
static bool isLegoTrain(const NimBLEAdvertisedDevice &adv) {
    if (!adv.haveManufacturerData()) return false;
    std::string m = adv.getManufacturerData();
    if (m.size() < 2) return false;
    return memcmp(m.data(), kLegoMfgPrefix, 2) == 0;
}

static void cleanupClient() {
    if (g_client) {
        NimBLEDevice::deleteClient(g_client);
        g_client = nullptr;
    }
    g_char = nullptr;
    g_haveTarget = false;
    g_lastSpeed = 0;
}

static void startScan() {
    if (g_scanRunning) return;
    NimBLEDevice::deleteAllBonds();
    g_advSeen = 0;
    NimBLEDevice::getScan()->start(0, false, false);
    g_scanRunning = true;
    Serial.println("BLE scan started");
}

class AdvCallbacks : public NimBLEScanCallbacks {
    void handleResult(const NimBLEAdvertisedDevice *adv) {
        g_advSeen++;
        if (g_advSeen <= 5 || (g_advSeen % 50 == 0)) {
            Serial.printf("Adv #%u from %s RSSI=%d\n", g_advSeen,
                          adv->getAddress().toString().c_str(), adv->getRSSI());
        }
        if (isLegoTrain(*adv)) {
            Serial.printf("Found Duplo Train at %s RSSI=%d\n",
                          adv->getAddress().toString().c_str(), adv->getRSSI());
            g_targetAddr = adv->getAddress();
            g_haveTarget = true;
            NimBLEDevice::getScan()->stop();
            g_scanRunning = false;
        }
    }
    void onResult(const NimBLEAdvertisedDevice *adv) override { handleResult(adv); }
    void onResult(NimBLEAdvertisedDevice *adv) { handleResult(adv); }
    void onScanEnd(NimBLEScanResults results) { g_scanRunning = false; }
    void onScanEnd(const NimBLEScanResults *results) { g_scanRunning = false; }
};

class ClientCallbacks : public NimBLEClientCallbacks {
    void onConnect(NimBLEClient *c) override {
        Serial.println("Connected");
        c->updateConnParams(24, 24, 0, 120);
    }
    void onDisconnect(NimBLEClient *c, int reason) override {
        Serial.printf("Disconnected (reason=%d)\n", reason);
        // Don't cleanup or scan from callback context; let loop() handle it
        g_char = nullptr;
    }
    bool onConnParamsUpdateRequest(NimBLEClient *c, const ble_gap_upd_params *params) override {
        return true;
    }
};

static ClientCallbacks g_clientCb;

static bool connectAndDiscover() {
    if (!g_haveTarget) return false;
    Serial.printf("Connecting to %s\n", g_targetAddr.toString().c_str());

    cleanupClient();
    g_haveTarget = true; // restore — cleanupClient clears it

    NimBLEDevice::deleteAllBonds();
    g_client = NimBLEDevice::createClient();
    g_client->setClientCallbacks(&g_clientCb, false);

    if (!g_client->connect(g_targetAddr)) {
        Serial.println("Connect failed");
        cleanupClient();
        delay(1000);
        startScan();
        return false;
    }

    NimBLERemoteService *svc = g_client->getService(kServiceUuid);
    if (!svc) {
        Serial.println("Service not found");
        g_client->disconnect();
        cleanupClient();
        startScan();
        return false;
    }

    g_char = svc->getCharacteristic(kCharUuid);
    if (!g_char) {
        Serial.println("Characteristic not found");
        g_client->disconnect();
        cleanupClient();
        startScan();
        return false;
    }

    if (g_char->canNotify()) {
        g_char->subscribe(true, [](NimBLERemoteCharacteristic *, uint8_t *data, size_t len, bool) {
            Serial.print("Notify: ");
            for (size_t i = 0; i < len; ++i) Serial.printf("%02X ", data[i]);
            Serial.println();
        });
    }

    Serial.println("Connected and ready");
    return true;
}

// ── Motor Control ────────────────────────────────────────
static const int SPEED_THRESHOLD = 3;            // ignore ADC jitter smaller than this
static const unsigned long MOTOR_MIN_MS = 200;   // minimum interval between motor writes
static unsigned long g_lastMotorMs = 0;

static void sendMotorSpeed(int speed) {
    if (!g_char) return;
    if (speed == 0) {
        g_char->writeValue(kStopPacket, sizeof(kStopPacket), false);
    } else {
        uint8_t absSpeed = constrain(abs(speed), 0, SPEED_MAX);
        kMotorPacket[7] = (speed > 0) ? 0x01 : 0x02; // fwd or bck
        kMotorPacket[9] = absSpeed;
        g_char->writeValue(kMotorPacket, sizeof(kMotorPacket), false);
    }
}

// ── Potentiometer ────────────────────────────────────────
static void handlePoti() {
    int raw = analogRead(POT_PIN);
    int speed = 0;
    int lo = POT_MID - POT_DEADBAND; // 1741
    int hi = POT_MID + POT_DEADBAND; // 2355

    if (raw < lo) {
        speed = map(raw, POT_MIN, lo, SPEED_MAX, 0);
    } else if (raw > hi) {
        speed = map(raw, hi, POT_MAX, 0, -SPEED_MAX);
    }

    // Detect potentiometer movement as user activity
    if (abs(raw - g_lastPotRaw) > POT_ACTIVITY_THRESHOLD) {
        g_lastPotRaw = raw;
        resetActivityTimer();
    }

    int diff = abs(speed - g_lastSpeed);
    // Always send on stop/start transitions; otherwise require threshold + minimum interval
    bool isTransition = (speed == 0) != (g_lastSpeed == 0);
    if (isTransition || (diff >= SPEED_THRESHOLD && millis() - g_lastMotorMs >= MOTOR_MIN_MS)) {
        sendMotorSpeed(speed);
        g_lastSpeed = speed;
        g_lastMotorMs = millis();
    }
}

// ── Buttons ──────────────────────────────────────────────
static void handleButtons() {
    bool anyPressed = false;
    if (pbStop.update() && pbStop.fell()) {
        g_char->writeValue(kStopPacket, sizeof(kStopPacket), true);
        g_lastSpeed = 0;
        Serial.println("Button: Stop");
        anyPressed = true;
    }
    if (pbHorn.update() && pbHorn.fell()) {
        g_char->writeValue(kHornPacket, sizeof(kHornPacket), true);
        Serial.println("Button: Horn");
        anyPressed = true;
    }
    if (pbLed.update() && pbLed.fell()) {
        g_ledIndex = (g_ledIndex + 1) % kNumLedColors;
        g_char->writeValue(kLedPackets[g_ledIndex], sizeof(kLedPackets[0]), true);
        Serial.printf("Button: LED color %u\n", (unsigned)g_ledIndex);
        anyPressed = true;
    }
    if (pbWater.update() && pbWater.fell()) {
        g_actionIndex = (g_actionIndex + 1) % kNumActions;
        g_char->writeValue(kActionPackets[g_actionIndex], sizeof(kActionPackets[0]), true);
        Serial.printf("Button: Action %u\n", (unsigned)g_actionIndex);
        anyPressed = true;
    }
    if (anyPressed) resetActivityTimer();
}

// ── Setup & Loop ─────────────────────────────────────────
void setup() {
    Serial.begin(115200);
    Serial.println("Duplo Train Remote (raw NimBLE)");

    if (esp_sleep_get_wakeup_cause() == ESP_SLEEP_WAKEUP_GPIO) {
        Serial.println("Woke up from deep sleep (button press)");
    }

    // Initialize activity timer and potentiometer baseline
    g_lastActivityMs = millis();
    g_lastPotRaw = analogRead(POT_PIN);

    // Buttons with Bounce2 debouncing
    pbStop.attach(BTN_STOP_PIN, INPUT_PULLUP);
    pbHorn.attach(BTN_HORN_PIN, INPUT_PULLUP);
    pbLed.attach(BTN_LED_PIN, INPUT_PULLUP);
    pbWater.attach(BTN_WATER_PIN, INPUT_PULLUP);
    pbStop.interval(DEBOUNCE_MS);
    pbHorn.interval(DEBOUNCE_MS);
    pbLed.interval(DEBOUNCE_MS);
    pbWater.interval(DEBOUNCE_MS);

    // BLE init
    NimBLEDevice::init("");
    NimBLEDevice::deleteAllBonds();
    NimBLEDevice::setPower(ESP_PWR_LVL_P9);
    NimBLEDevice::setSecurityAuth(true, true, true);
    NimBLEDevice::setSecurityIOCap(BLE_HS_IO_NO_INPUT_OUTPUT);
    NimBLEDevice::setOwnAddrType(BLE_OWN_ADDR_RANDOM);

    NimBLEScan *scan = NimBLEDevice::getScan();
    scan->setScanCallbacks(new AdvCallbacks(), true);
    scan->setInterval(45);
    scan->setWindow(30);
    scan->setActiveScan(true);

    Serial.println("Starting BLE scan...");
    bool ok = scan->start(0, false, false);
    Serial.printf("Scan start %s\n", ok ? "ok" : "FAILED");
    g_scanRunning = ok;
}

void loop() {
    // Check inactivity timeout — sleep if idle too long
    if (millis() - g_lastActivityMs >= SLEEP_TIMEOUT_MS) {
        enterDeepSleep();
    }

    // Detect disconnection: client exists but lost connection
    if (g_client && !g_client->isConnected()) {
        Serial.println("Connection lost; cleaning up");
        cleanupClient();
        delay(1000);
        startScan();
    }

    // Not connected: scan and connect
    if (!g_client) {
        if (g_haveTarget) {
            connectAndDiscover();
        } else if (!g_scanRunning) {
            startScan();
        } else {
            unsigned long now = millis();
            if (now - g_lastScanLogMs > 3000) {
                Serial.printf("Scanning... advSeen=%u\n", g_advSeen);
                if (!NimBLEDevice::getScan()->isScanning()) {
                    Serial.println("Scan stopped unexpectedly; restarting");
                    g_scanRunning = false;
                    startScan();
                }
                g_lastScanLogMs = now;
            }
        }
        delay(50);
        return;
    }

    // Connected: handle inputs
    handleButtons();
    handlePoti();
    delay(LOOP_DELAY_MS);
}

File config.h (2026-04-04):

#pragma once

// ── XIAO ESP32S3 Pin Mapping ───────────────────────────
#define POT_PIN         2       // D1 / GPIO2 - Potentiometer (speed)
#define BTN_WATER_PIN   3       // D2 / GPIO3 - Water/action cycle
#define BTN_HORN_PIN    4       // D3 / GPIO4 - Horn sound
#define BTN_STOP_PIN    5       // D4 / GPIO5 - Stop (brake)
#define BTN_LED_PIN     6       // D5 / GPIO6 - LED color cycle

// ── Potentiometer ──────────────────────────────────────
#define POT_DEADBAND    150     // +/- around midpoint (2048) ~7% of 4096
#define POT_MID         2048
#define POT_MIN         350     // actual pot minimum (tune to hardware)
#define POT_MAX         3750    // actual pot maximum (tune to hardware)

// ── Button Timing (ms) ────────────────────────────────
#define DEBOUNCE_MS     50

// ── Train Speed ────────────────────────────────────────
#define SPEED_MAX       100

// ── Auto Power-Off (deep sleep) ───────────────────────
#define SLEEP_TIMEOUT_MS  300000  // 5 minutes of inactivity
#define POT_ACTIVITY_THRESHOLD 50 // ADC change to count as activity

// ── Loop ───────────────────────────────────────────────
#define LOOP_DELAY_MS   50

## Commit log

2026-02-10 Duplo Train remote control firmware for XIAO ESP32S3
    Raw NimBLE 2.x BLE connection to Duplo Train Hub with direct LWP3
    packet writes. Features variable speed via potentiometer (GPIO2),
    debounced buttons for horn (GPIO4), stop/brake (GPIO5), LED color
    cycle (GPIO6), and water/action cycle (GPIO3). Includes automatic
    reconnection on disconnect with proper client cleanup.
2026-02-10 Add README with hardware wiring, features, and protocol docs
2026-04-04 Add auto power-off via deep sleep after 5 minutes of inactivity
    ESP32-S3 enters deep sleep (~10uA) when no button press or
    potentiometer movement is detected for 5 minutes. Any of the
    four buttons wakes the remote back up. BLE is cleanly
    disconnected before sleep.
2026-04-11 Fix deep sleep compilation errors: add forward declaration and use correct wakeup API
    cleanupClient() was called before its definition, and esp_deep_sleep_enable_gpio_wakeup
    is not available in ESP-IDF 4.4. Use esp_sleep_enable_ext1_wakeup with ESP_EXT1_WAKEUP_ANY_LOW instead.
    [main.cpp]
2026-07-20 Add CAD/model files for ESP32 Duplo train remote
    [BOX SC V2.stp, BOX SC v2.3mf, Topplaat.stp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]
